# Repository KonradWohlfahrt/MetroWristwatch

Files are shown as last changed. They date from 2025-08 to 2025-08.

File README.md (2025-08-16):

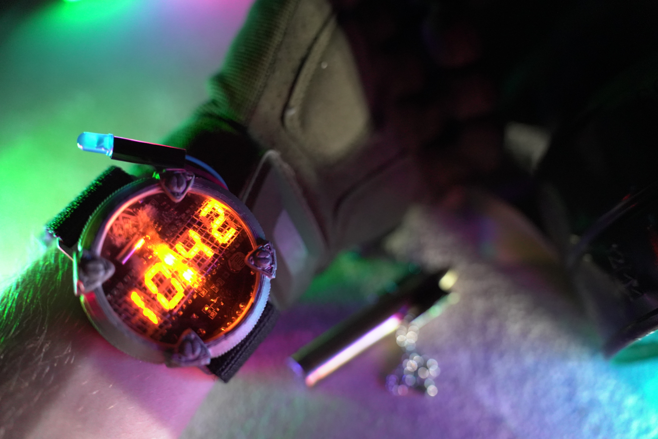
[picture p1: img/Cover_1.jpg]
Cover


# METRO WRISTWATCH
**Artyom’s Watch - Metro Series Inspired Wristwatch**

Ever wanted to build a piece of your favorite video game in real life? This project brings Artyom’s iconic wristwatch from the Metro game series into the real world! Designed to be both nostalgic and functional, this DIY gadget keeps time, adapts screen brightness to the environment, and stays true to the post-apocalyptic style of the original. Some design tweaks were made to simplify the build: 7-segment displays instead of nixie tubes, microcontroller is housed separately to save PCB space.
A full build guide is available at instructables: [https://www.instructables.com/Artyoms-Wristwatch-From-Metro/](https://www.instructables.com/Artyoms-Wristwatch-From-Metro/)

If you build your own version, feel free to share it or fork this project - I’d love to see what you come up with!

***
# FEATURES
- Low power microcontroller (XIAO nRF52840)
- 7-segment LED display
- DS1302 real time clock IC, date and time display
- 5-minute timer
- Adjustable display brightness with LDR
- 6+ days battery life in testing

***
# PROGRAMMING
Programmed with the Arduino IDE and [XIAO nRF52840 board manager](https://wiki.seeedstudio.com/XIAO_BLE/#getting-started). Only one external library is required, everything else is included: [Ds1302](https://github.com/Treboada/Ds1302).

***
# ELECTRIC COMPONENTS:
| Component | Amount | Silkscreen label |
|:---|:---:|---:|
| Custom PCB | 1 | - |
| TH CR927 Battery Clip | 1 | BT1 |
| 100nF 0805 | 2 | C1,C2 |
| PH2.0 2 Pin Connector | 1 | CN1 |
| 4x 7-segment LED, Yellow (Everlight ELSS406) | 4 | LED1-4 |
| 0805 SMD LED, Yellow | 2 | LED5,LED6 |
| 5mm LED, Blue | 1 | - |
| MMBT2222A | 2 | Q1,Q2 |
| 7mm LDR | 2 | - |
| 1k 0805 | 3 | R2,R6,R9 |
| 10k 0805 | 2 | R3,R4 |
| 220r 0805 | 3 | R5,R7,R8 |
| Horizontal tactile switch 6x6x3mm | 2 | SW1,SW2 |
| SK12D07VG3 | 1 | SW3 |
| TM1637 | 1 | U1 |
| DS1302 | 1 | U2 |
| 32.768kHz Crystal 6pF | 1 | X1 |
| XIAO nRF52840 | 1 | - |
| 100mAh LiPo Battery | 1 | - |

***
# GALLERY
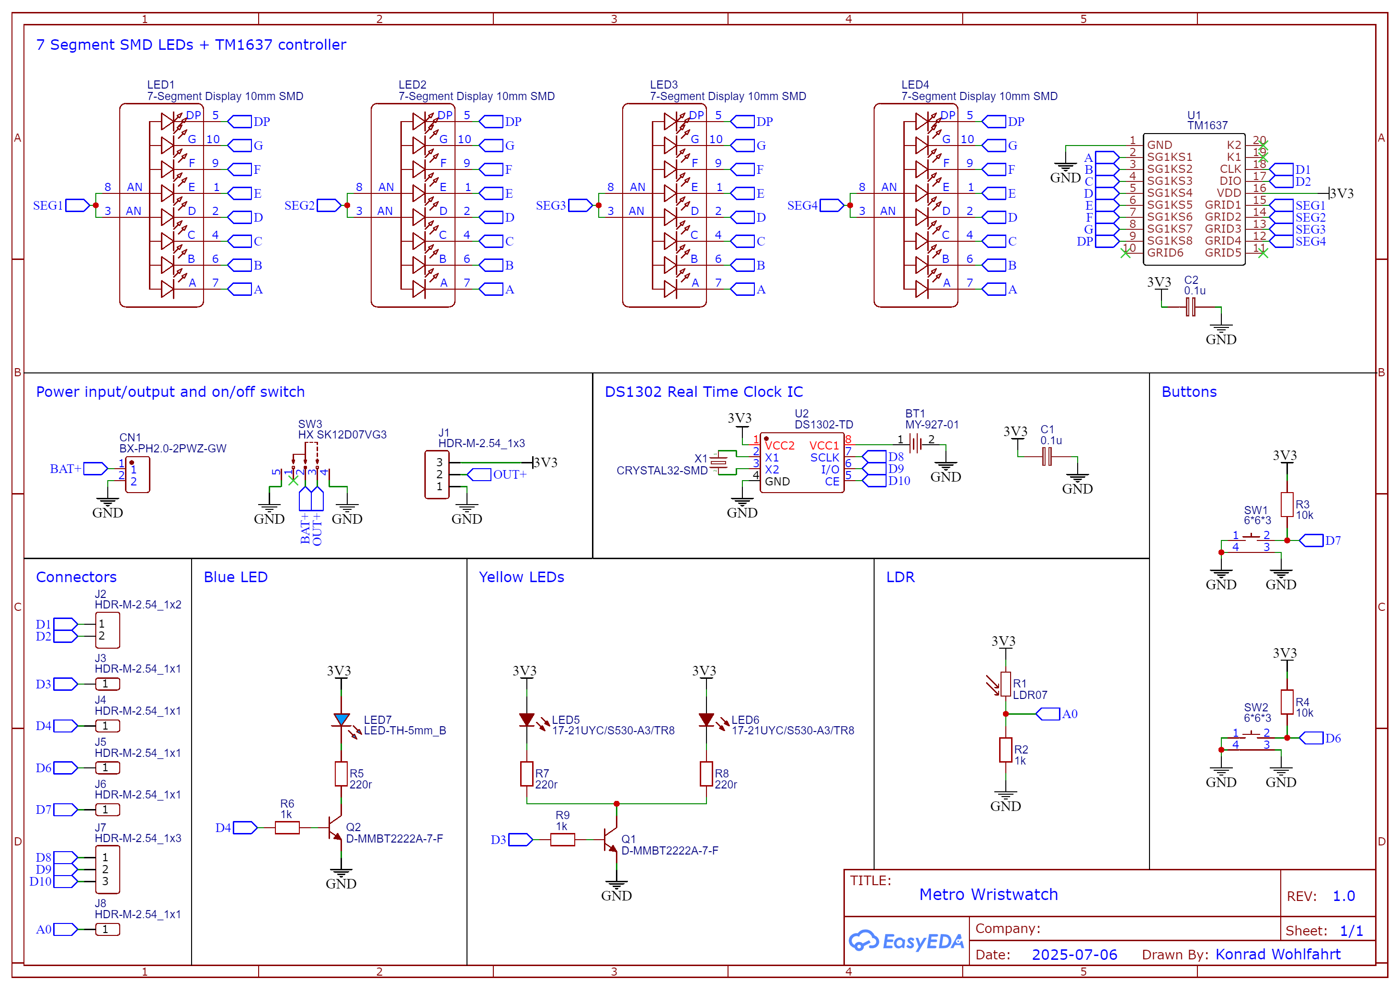
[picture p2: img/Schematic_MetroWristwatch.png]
Schematic

_Schematic of the Focus Wheel_
PCB Lables Front
_SMD component placement reference (front)_
PCB Lables Back
_SMD component placement reference (back)_
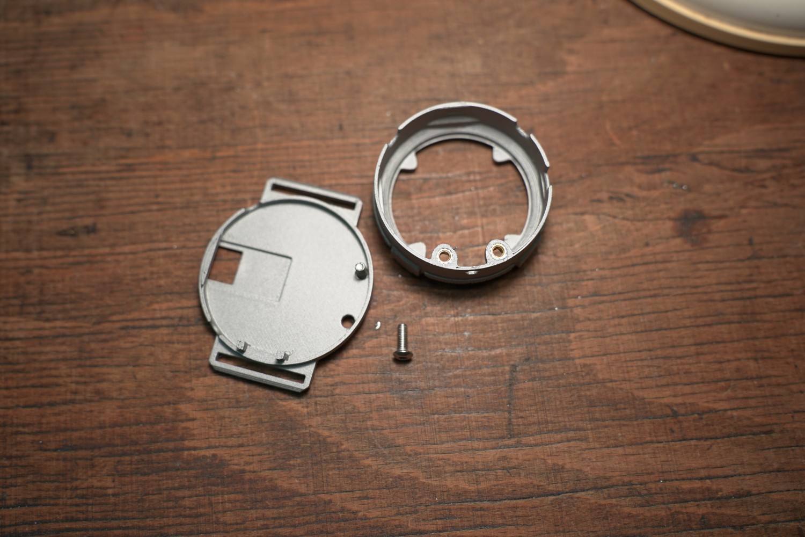
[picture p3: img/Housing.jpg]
Housing

_3D printed and spray painted housing_

***
# FUNCTIONS
The button facing towards you is the **MODE** button, and the one facing away from you is the **SET** button. The **MODE** button is used to navigate the different menues (Time -> Date -> Timer) and changing the selected settings. The **SET** button switches between the displayed information (Time: HH:MM -> xx:SS; Date: Weekday -> DD.MM -> YYYY), starts the timer and changes the selected setting (hold for fast-forward). Press and hold **MODE**, then press **SET** to enter or exit the settings menu of the current mode.

The watch will return to deep sleep after a few seconds to preserve power, it can be woken up by pressing any button. Once the battery runs low, a message will appear before entering sleep mode. If too low, the watch will instantly go back to sleep mode. Charging the battery through the USB-C port will show the current percentage and an charging animation.

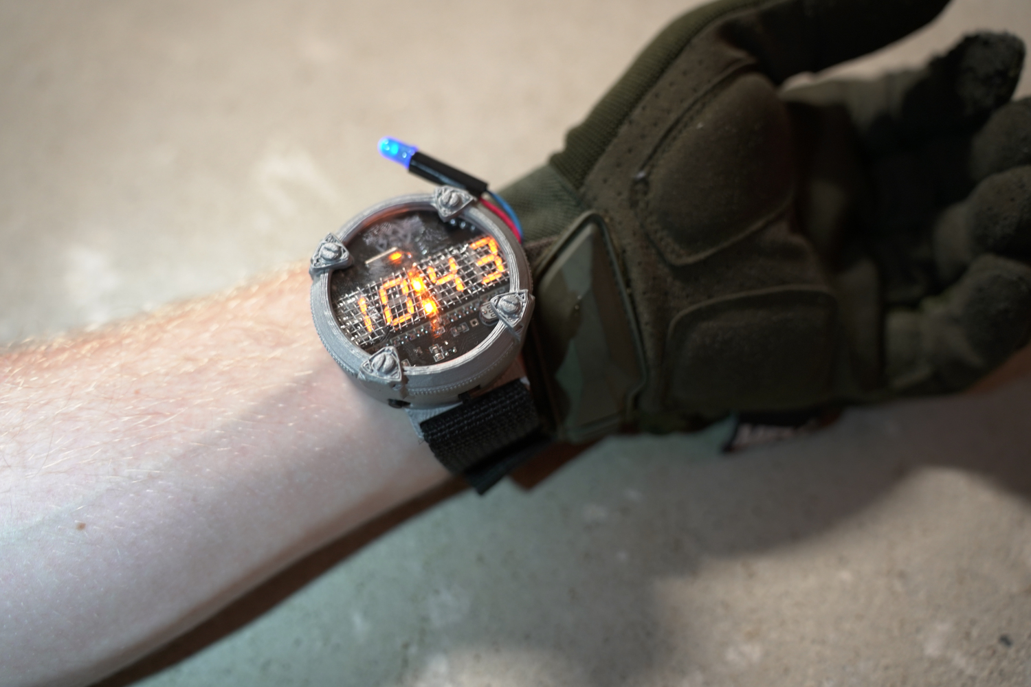
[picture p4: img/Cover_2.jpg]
Metro Wristwatch


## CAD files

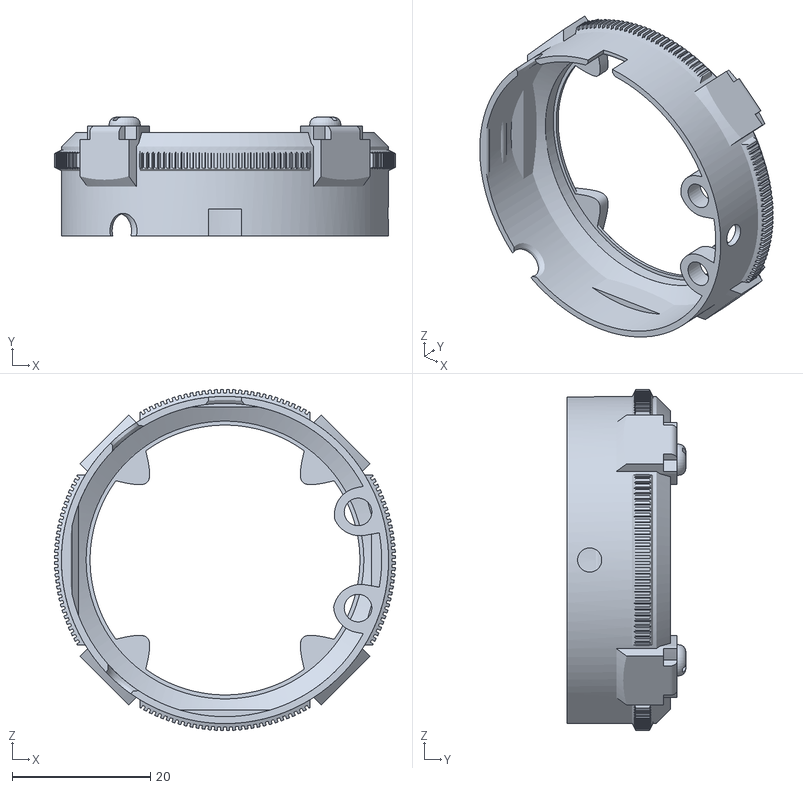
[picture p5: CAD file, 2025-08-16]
cad/Watch Housing.stl
49.3 x 17.1 x 49.3

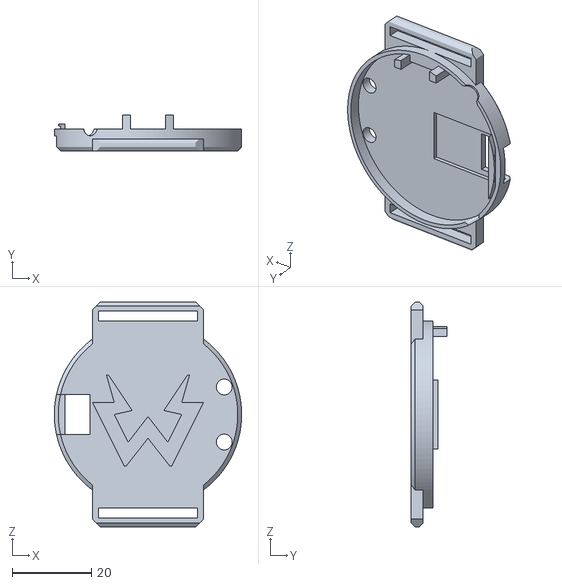
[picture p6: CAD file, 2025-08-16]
cad/Bottom Lid.stl
47.3 x 9.00 x 56.8

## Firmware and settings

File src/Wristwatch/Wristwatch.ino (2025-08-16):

#include "preferences.h"

#define DISP_REFRESH_TIME 100

const char SEG_Weekday[7][2] = {
  ///* ENG
  { 'm', 'o' },
  { 't', 'u' },
  { 'w', 'e' },
  { 't', 'h' },
  { 'f', 'r' },
  { 's', 'a' },
  { 's', 'u' }
  //*/

  /* GER
  { 'm', 'o' },
  { 'd', 'i' },
  { 'm', 'i' },
  { 'd', 'o' },
  { 'f', 'r' },
  { 's', 'a' },
  { 's', 'o' }
  //*/
};

void checkBrightness(bool ignore = false);
void refreshPeripherals();
void refreshMode();
void changeMode();
void showBatteryPercent();
void checkBattery(bool ignore = false);


uint32_t _brightnessTimestamp;
void checkBrightness(bool ignore)
{
  // update brightness of the display every 1s
  if (isTimestamp(_brightnessTimestamp, 1000) || ignore)
    disp.setBrightness(getBrightness(0, 7), false);
}
void checkBlueLED()
{
  // divide by 2 to lower brightness & save energy
  analogWrite(BLUE_LED_PIN, getBrightness() / 2);
}

#define SLEEP_TIME 10000
uint32_t _interactionTimestamp;
void startDeepSleep()
{
  // configure wakeup pins
  nrf_gpio_cfg_sense_input(g_ADigitalPinMap[SET_BTN], NRF_GPIO_PIN_NOPULL, NRF_GPIO_PIN_SENSE_LOW);
  nrf_gpio_cfg_sense_input(g_ADigitalPinMap[MODE_BTN], NRF_GPIO_PIN_NOPULL, NRF_GPIO_PIN_SENSE_LOW);
  delay(500);
  // go to deep sleep
  sd_power_system_off();
  NRF_POWER->SYSTEMOFF = 1;
}
void checkSleepmode()
{
  if (isTimestamp(_interactionTimestamp, SLEEP_TIME))
  {
    // show battery percent if below or equal to 20%
    if (battery.GetBatteryPercent() <= 20)
    {
      playAnimation(new uint8_t[4] { 'l', 'o', 'w', 10 });
      delay(500);
      playAnimation(new uint8_t[4] { 'b', 'a', 't', 10 });
      delay(500);
      showBatteryPercent();
      delay(500);
    }

    playAnimation(new uint8_t[4] { 10, 10, 10, 10 });

    disp.enableDisplay(false);
    setColonLEDs(false);
    setBlueLED(false);

    startDeepSleep();
  }
}


#define BAT_CHECK_TIME 1000
uint32_t _batCheckTimestamp;
void showBatteryPercent()
{
  uint8_t p = battery.GetBatteryPercent();
  if (p == 100)
    playAnimation(new uint8_t[4] { 10, 1, 0, 0 });
  else if (p >= 10)
    playAnimation(new uint8_t[4] { 10, 10, p / 10, p % 10 });
  else
    playAnimation(new uint8_t[4] { 10, 10, 10, p });
}
void checkBattery(bool ignore)
{
  if (isTimestamp(_batCheckTimestamp, BAT_CHECK_TIME) || ignore)
  {
    // check if the battery is charging
    if (battery.IsChargingBattery()) 
    {
      showBatteryPercent();

      setBlueLED(false);
      setColonLEDs(false);
      disp.setBrightness(7, false);

      uint8_t animIndex = 0;
      const uint8_t animSegmentIndex[4] = { 0, 1, 6, 5 };
      while (battery.IsChargingBattery())
      {
        // show only even percentage (reduce flickering)
        uint8_t p = battery.GetBatteryPercent();
        if (p % 2 != 0)
          p -= 1;
        disp.setNumber(p);

        disp.setDigitSegment(0, animSegmentIndex[animIndex], true);
        disp.show();
        animIndex = (animIndex + 1) % 4;

        delay(75);
      }

      NVIC_SystemReset();
    }
    // check if the battery is low
    if (battery.GetBatteryPercent() <= 10)
    {
      disp.setBrightness(0, false);

      playAnimation(new uint8_t[4] { 'l', 'o', 'w', 10 });
      delay(500);
      playAnimation(new uint8_t[4] { 'b', 'a', 't', 10 });
      delay(500);
      showBatteryPercent();
      delay(500);
      playAnimation(new uint8_t[4] { 10, 10, 10, 10 });
      
      disp.enableDisplay(false);
      setColonLEDs(false);
      setBlueLED(false);

      startDeepSleep();
    }
  }
}


#include "Modes.h"
const int _modesCount = 3;
uint8_t _currentModeIndex = 0;
WristwatchMode * _modes[] = { new TimeDisplay(), new DateDisplay(), new TimerDisplay() };
WristwatchMode * _currentMode;

uint32_t refreshTimestamp;

void setup() 
{
  //Serial.begin(115200);

  pinMode(SET_BTN, INPUT);
  pinMode(MODE_BTN, INPUT);
  pinMode(LDR_PIN, INPUT);

  pinMode(COLON_LEDS_PIN, OUTPUT);
  setColonLEDs(false);
  pinMode(BLUE_LED_PIN, OUTPUT);
  setBlueLED(false);

  analogReadResolution(12); // Can be 8, 10, 12 or 14 bit

  // INITIALIZE RTC
  rtc.init();
  if (rtc.isHalted())
  {
    Ds1302::DateTime dt = {
      .year = 33,
      .month = Ds1302::MONTH_JAN,
      .day = 1,
      .hour = 12,
      .minute = 0,
      .second = 0,
      .dow = Ds1302::DOW_SAT
    };
    rtc.setDateTime(&dt);
  }

  checkBattery(true);
  checkBrightness(true);
  changeMode();
}
void loop() 
{
  // MODE BUTTON - switch between modes
  if (isMode())
  {
    bool both = false;
    while (isMode())
    {
      refreshMode();
      if (!both && isSet())
        both = true;
      delay(2);
    } 

    if (!both) 
    {
       _currentModeIndex = (_currentModeIndex + 1) % _modesCount;
      changeMode();
    }
    else
      _currentMode->onBothButtons();
   
    _interactionTimestamp = millis();
  }

  // SET BUTTON
  if (isSet())
  {
    while (isSet())
    {
      refreshMode();
      delay(2);
    }

    _currentMode->onSetButton();
    _interactionTimestamp = millis();
  }

  refreshMode();
}


void refreshPeripherals()
{
  checkBrightness();
  checkBlueLED();
  checkBattery();
}
void refreshMode()
{
  if (isTimestamp(refreshTimestamp, DISP_REFRESH_TIME))
  {
    _currentMode->onUpdate();
    checkSleepmode();
  }
  refreshPeripherals();
}
void changeMode()
{
  _currentMode = _modes[_currentModeIndex];
  _currentMode->onStart();
  setColonLEDs(false);
}

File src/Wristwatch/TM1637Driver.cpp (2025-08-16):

#include "Arduino.h"
#include "TM1637Driver.h"

#define DISPLAY_LENGTH 4

#define TM1637_WRITE_DELAY 100

#define TM1637_DATA_COMMAND 0x40
#define TM1637_DISPLAY_CONTROL_COMMAND 0x80 
#define TM1637_ADDRESS_COMMAND 0xC0


TM1637::TM1637(uint8_t pinDIO, uint8_t pinCLK)
{
  _pinDIO = pinDIO;
  _pinCLK = pinCLK;

  pinMode(pinCLK, OUTPUT);
  pinMode(pinDIO, OUTPUT);
	digitalWrite(pinCLK, LOW);
	digitalWrite(pinDIO, LOW);
}

void TM1637::setBrightness(uint8_t brightness, bool refresh)
{
  _brightness = brightness & 0x07;
  if (refresh)
    show();
}
uint8_t TM1637::getBrightness()
{
  return _brightness;
}

void TM1637::enableDisplay(bool enable, bool refresh)
{
  _enabled = enable;
  if (refresh)
    show();
}
bool TM1637::enabled()
{
  return _enabled;
}

void TM1637::clear()
{
  for (int i = 0; i < DISPLAY_LENGTH; i++)
    _displayBuffer[i] = 0x00;
}
void TM1637::move(int8_t shift)
{
  if (shift == 0)
    return;

  if (shift > 0)
  {
    for (int8_t i = 0; i < DISPLAY_LENGTH; i++)
    {
      int8_t newDigit = i + shift;
      if (digitInRange(newDigit))
        _displayBuffer[i] = _displayBuffer[newDigit];
      else
        _displayBuffer[i] = 0x00;
    }
  }
  else
  {
    for (int8_t i = DISPLAY_LENGTH - 1; i >= 0; i--)
    {
      int8_t newDigit = i + shift;
      if (digitInRange(newDigit))
        _displayBuffer[i] = _displayBuffer[newDigit];
      else
        _displayBuffer[i] = 0x00;
    }
  }
}
void TM1637::setSegments(const uint8_t* segments)
{
  uint8_t size = sizeof(segments) / sizeof(segments[0]);
  for (uint8_t i = 0; i < DISPLAY_LENGTH; i++)
  {
    if (i <= size)
      _displayBuffer[i] = segments[i];
    else
      _displayBuffer[i] = 0x00;
  }
}
void TM1637::setNumber(int16_t number, bool leadZeros)
{
  bool negativ = number < 0;
  if (negativ)
    number = -number;
  bool begun = false;

  for (uint8_t i = 0; i < DISPLAY_LENGTH; i++)
  {
    if (negativ && leadZeros && i == 0)
    {
      _displayBuffer[i] = _segments[6]; // minus
      negativ = false;
      continue;
    }

    uint8_t digit = (number / (uint16_t)pow(10, DISPLAY_LENGTH - 1 - i)) % 10;
    if (!begun && digit == 0 && i < DISPLAY_LENGTH - 1)
    {
      if (leadZeros)
        _displayBuffer[i] = _numbers[digit];
      else 
      {
        digit = (number / (uint16_t)pow(10, DISPLAY_LENGTH - 2 - i)) % 10;
        if (negativ && digit != 0)
          _displayBuffer[i] = _segments[6];
        else
          _displayBuffer[i] = 0x00;
      }
    }
    else
    {
      _displayBuffer[i] = _numbers[digit];
      begun = true;
    }
  }
}
void TM1637::setDigit(uint8_t index, uint8_t digit)
{
  if (digitInRange(index))
    _displayBuffer[index] = digit;
}
uint8_t TM1637::getDigit(uint8_t index)
{
  if (digitInRange(index))
    return _displayBuffer[index];
  return 0x00;
}
void TM1637::setDigitSegment(uint8_t digitIndex, uint8_t segmentIndex, bool value)
{
  if (!digitInRange(digitIndex) || !segmentInRange(segmentIndex))
    return;
  
  if (value)
    _displayBuffer[digitIndex] = _displayBuffer[digitIndex] | _segments[segmentIndex];
  else
    _displayBuffer[digitIndex] = _displayBuffer[digitIndex] & (~_segments[segmentIndex]);
}
bool TM1637::getDigitSegment(uint8_t digitIndex, uint8_t segmentIndex)
{
  if (!digitInRange(digitIndex) || !segmentInRange(segmentIndex))
    return false;
  return (_displayBuffer[digitIndex] & _segments[segmentIndex]) != 0;
}

void TM1637::show()
{
  start();
  writeByte(TM1637_DATA_COMMAND); // indicate data write to display register
  stop();

  start();
  writeByte(TM1637_ADDRESS_COMMAND); // write display address command (start: C0H)
	for (uint8_t i = 0; i < DISPLAY_LENGTH; i++)
	  writeByte(_displayBuffer[i]); // write each digit data
	stop();

  start();
  writeByte(TM1637_DISPLAY_CONTROL_COMMAND | _brightness | (_enabled ? 0x08 : 0x00)); // write brightness & on/off
  stop();
}


uint8_t TM1637::getNumber(uint8_t number)
{
  if (number < 0 || number > 9)
    return 0x00;
  return _numbers[number];
}
uint8_t TM1637::getCharacter(char character)
{
  character = tolower(character);

  if (isAlpha(character))
    return _alphabet[(character - 97)];
  if (isDigit(character))
    return _numbers[(character - 48)];

  switch (character)
  {
    case '-':
      return _segments[6];
    case '.':
      return _segments[7];
    case '_':
      return _segments[3];
    case ',':
      return _specialCharacters[0];
    case '!':
      return _specialCharacters[1];
    case '?':
      return _specialCharacters[2];
    case '=':
      return _specialCharacters[3];
    case '>':
      return _specialCharacters[4];
    case '<':
      return _specialCharacters[5];
    case '(':
      return _specialCharacters[6];
    case ')':
      return _specialCharacters[7];
    case '/':
      return _specialCharacters[8];
    case '*':
      return _specialCharacters[9];
    case '"':
      return _specialCharacters[10];
    case '^':
      return _specialCharacters[11];
  }

  return 0x00;
}


bool TM1637::digitInRange(int8_t digit)
{
  return 0 <= digit && digit < DISPLAY_LENGTH;
}
bool TM1637::segmentInRange(int8_t segment)
{
  return 0 <= segment && segment < 8;
}

void TM1637::start()
{
  digitalWrite(_pinDIO, LOW); // pull dio low: indicate data input
  writeDelay();
}
void TM1637::stop()
{
  digitalWrite(_pinDIO, LOW); // keep dio low for one clk pulse
	writeDelay();

	digitalWrite(_pinCLK, HIGH); // clk high
	writeDelay();
	digitalWrite(_pinDIO, HIGH); // dio high
	writeDelay();
}
bool TM1637::writeByte(uint8_t data)
{
  // write byte to tm1637 via two-wire-interface
  uint8_t pointer = 1;
  for (uint8_t i = 0; i < 8; i++)
  {
    digitalWrite(_pinCLK, LOW); // clk pulse low
    writeDelay();

    digitalWrite(_pinDIO, (data & pointer) > 0 ? HIGH : LOW); // write bit on dio
    writeDelay();

    digitalWrite(_pinCLK, HIGH); // clk pulse high
    writeDelay();

    pointer = pointer << 1; // move to next bit pointer
  }

  // wait for ack, dio high (pulled down by tm1637)
  digitalWrite(_pinCLK, LOW);
  digitalWrite(_pinDIO, HIGH);
  writeDelay();

  digitalWrite(_pinCLK, HIGH); // clk pulse high
  writeDelay();

  // read ack signal
  uint8_t ack = digitalRead(_pinDIO);
  if (ack == 0)
    digitalWrite(_pinDIO, LOW);
  writeDelay();

  digitalWrite(_pinCLK, LOW);
  writeDelay();

  return ack;
}
void TM1637::writeDelay()
{
  delayMicroseconds(TM1637_WRITE_DELAY);
}
